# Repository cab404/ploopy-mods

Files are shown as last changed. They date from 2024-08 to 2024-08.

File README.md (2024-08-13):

cab's ploopy mods
====

This repo contains several of my small projects aimed to make Ploopy Headphones more comfortable for me — and maybe for you too.

They are mostly in dense OpenSCAD.

## [Newcap](./newcap/)

Stock magnet holders (driver caps) are not optimized for volume output.
This model improves volume dramatically (20dB+) by tweaking distance to the driver, magnet alignment and openness.

## [Headband](./headband/)

Ploopy headband is comfortable, but is not fit for listening on the move.
This model sits tighter — tight enough to  ride on an electric scooter — yet is still comfortable enough to enjoy.

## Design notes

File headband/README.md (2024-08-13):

Headband
====

I am currently using [r=50 without coils](./export/band+coils=....0+th=....2+r=...50.stl).

## How to choose

The lower the `r`, the more closed default position is.
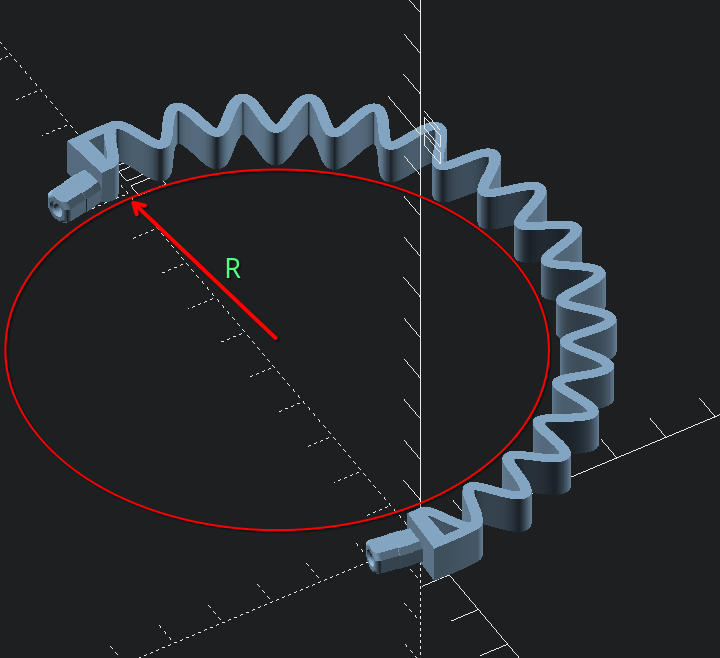
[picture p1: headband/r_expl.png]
image showing radius parameter


Thickness (`th`) can increase clamping force, but may also result in more brittle prints.

With [th=4 and r=30](./export/band+coils=....0+th=....4+r=...30.stl) you'll most probably get watermelon-between-thighs type of fit, so this repo truly offers wide range of experiences.

I haven't really experimented with number of coils yet, but I guess more coils can increase cushoning?
They do look kinda fun, and I've spent some time programming them, so do give them a try and report <3

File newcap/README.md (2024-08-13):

Newcap
====
This took forever, but they sure do plop louder now.
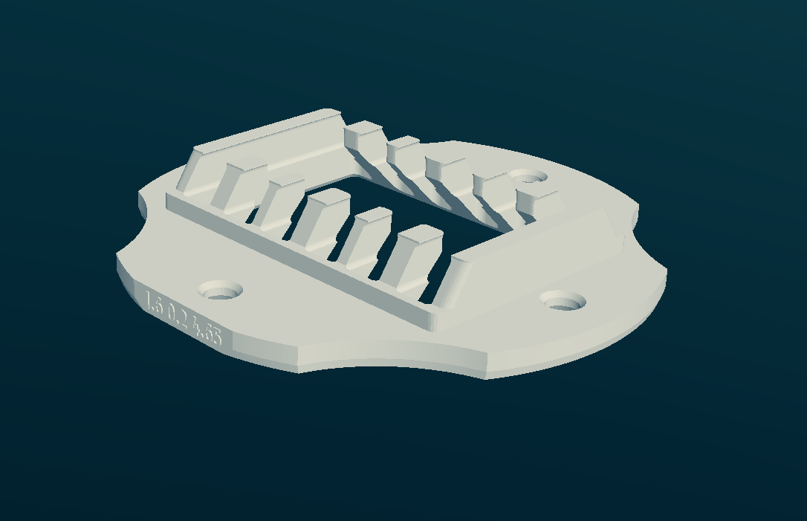
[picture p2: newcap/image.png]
open cap image, just for title

I am using [open 1.6 with 4.5 magnets, on 0.2 layer height](export/newcap+magnet_size=..4.5+open=..yes+h=..1.6+layer_height=..0.2.stl).

## How to choose

`magnet_size`: First of all, check your magnet width. It is usually 4.5mm, but I've encountered stock magnets being 4.8mm. Please report if you have some other different magnets.

`open`: This controls whether the holder exposes the driver, making the sound a lot more open, but also giving a lot more surface area for metal shavings and junk to stick to.

I find open variant nicer, and with less distortions, but Oratory is yet to test any of those caps on professional equipment.

`h`: This controls distance to inducer. The higher the value, the closer the magnets are.
Default is 1.6, but there is some variation in driver assemblies, so you might enjoy higher volumes on 1.8+ without any distortion.

`layer_height`: Top layer depends on print layer height. Printing on 0.1 can save you 0.1mm of potential travel for inducer, so it is recommended.

## How to install

You will either need either to cut some plastic from stock drivers or print [ones Xylite modelled](https://www.thingiverse.com/thing:6560552).

### Cutting plastic
You'll need to remove several perimeters (0.5mm) from the sides of driver frames, so the cap can with with magnets.

Here you can see where exactly you should cut:
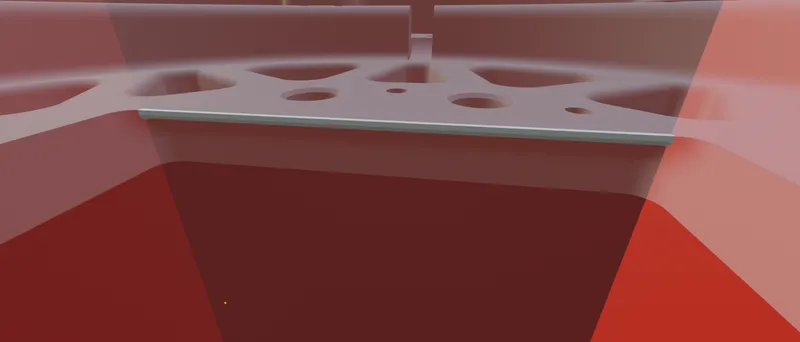
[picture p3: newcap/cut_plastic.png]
cut here


**Cut with drivers disassembled** if you are not completely sure that you won't destroy your inducer in the process.

Ploopy wiki for how to assemble the drivers back is [here](https://github.com/ploopyco/headphones/wiki/Part-2%3A-Drivers).

Don't rush.

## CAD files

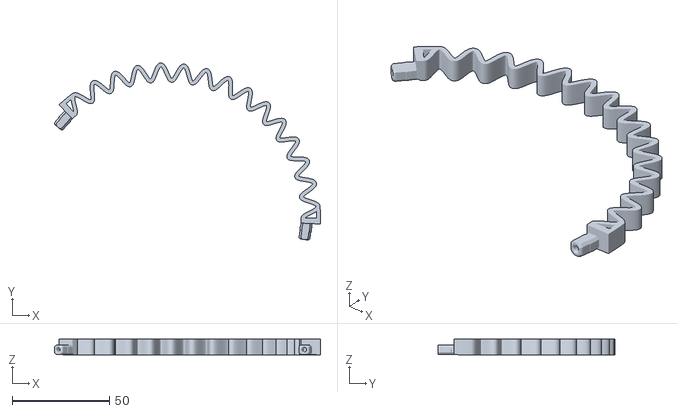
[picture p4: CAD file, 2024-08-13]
headband/export/band+coils=...15+th=....2+r=...70.stl
137.0 x 91.3 x 8.00

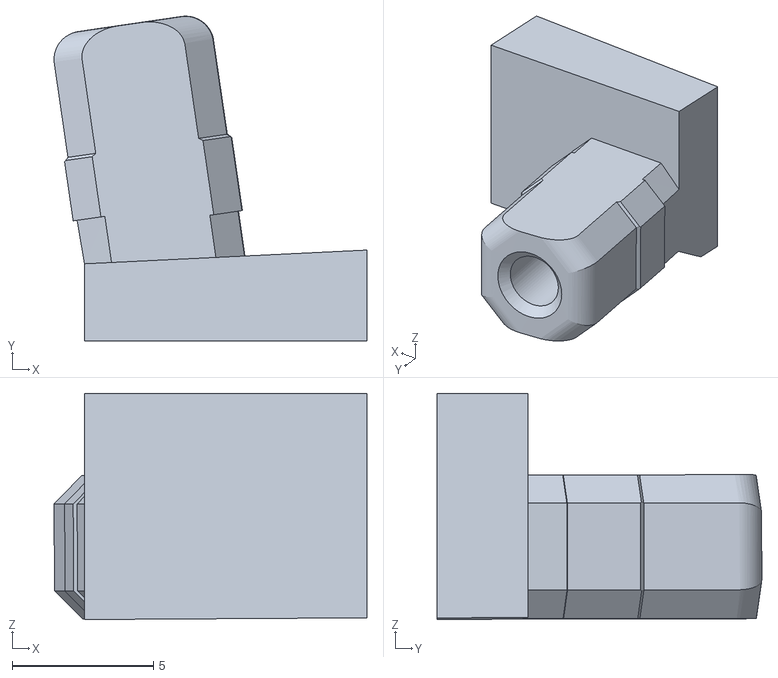
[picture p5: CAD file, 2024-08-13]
headband/pin.stl
11.1 x 11.5 x 8.00

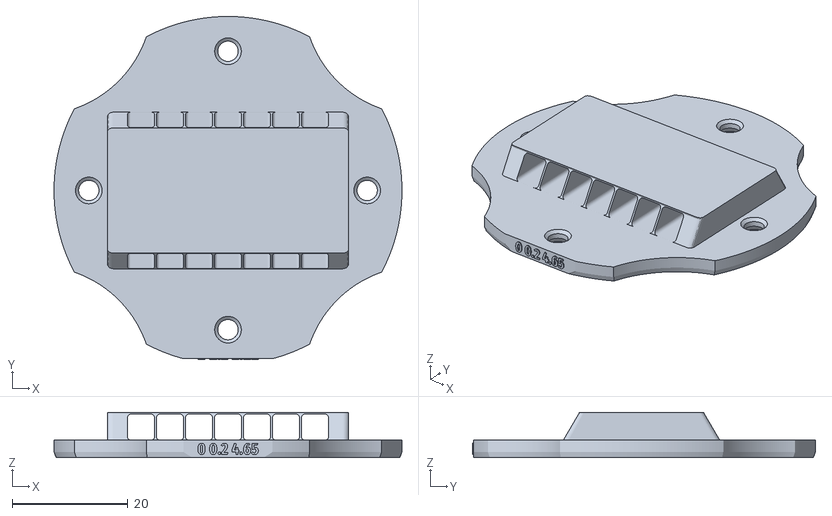
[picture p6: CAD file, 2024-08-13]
newcap/experiments/hallbachcap.stl
60.0 x 59.1 x 7.80

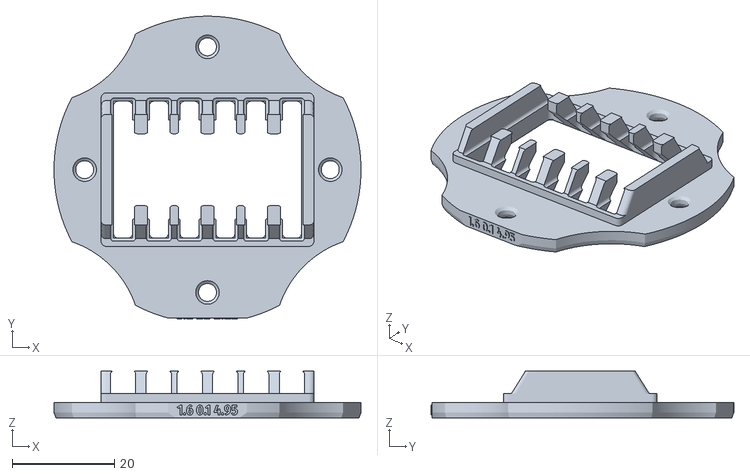
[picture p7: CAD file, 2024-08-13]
newcap/export/newcap+magnet_size=..4.8+open=..yes+h=..1.6+layer_height=..0.1.stl
60.0 x 59.1 x 9.10

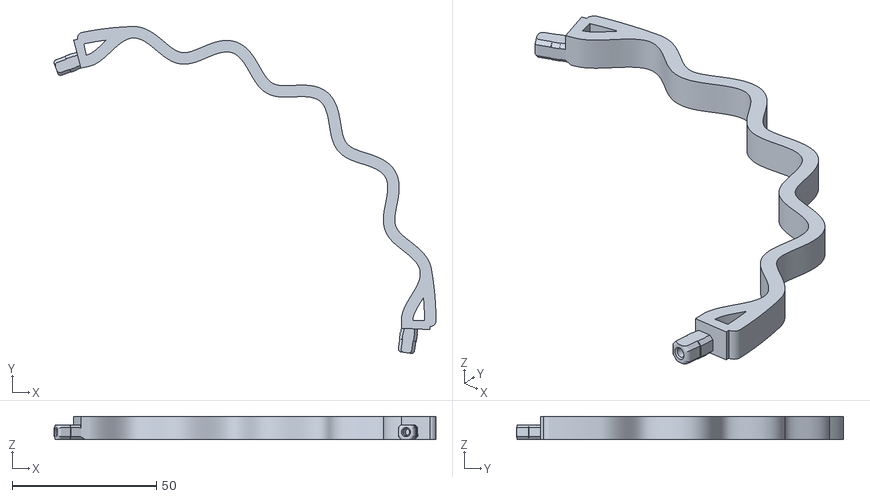
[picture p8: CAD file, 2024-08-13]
headband/export/band+coils=....5+th=....4+r=...90.stl
132.3 x 113.3 x 8.00

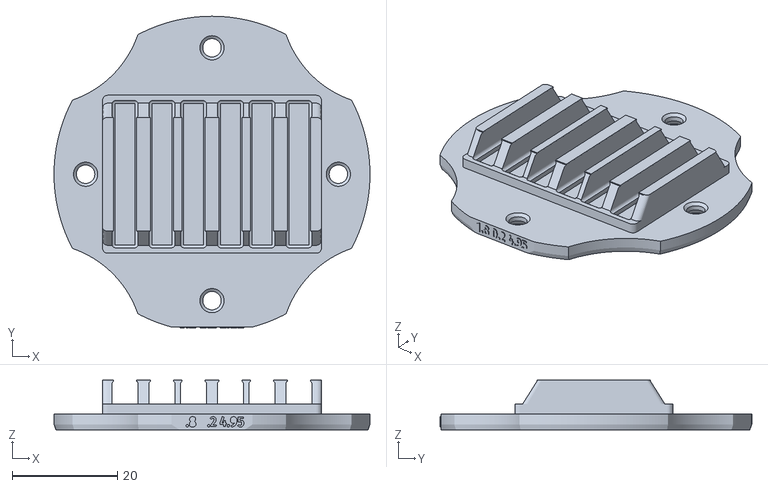
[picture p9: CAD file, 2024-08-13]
newcap/export/newcap+magnet_size=..4.8+open=...no+h=..1.8+layer_height=..0.2.stl
60.0 x 59.1 x 9.40

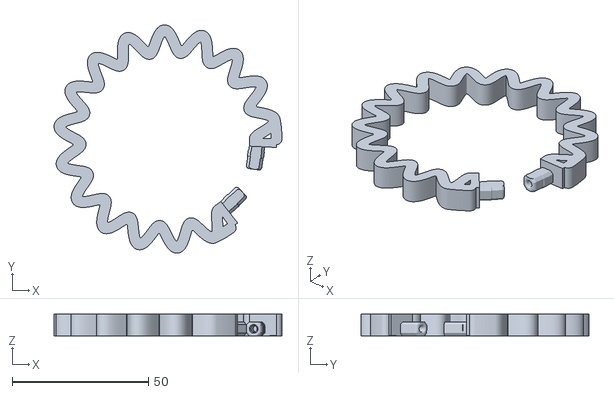
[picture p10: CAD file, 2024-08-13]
headband/export/band+coils=...15+th=....4+r=...30.stl
83.7 x 83.8 x 8.00

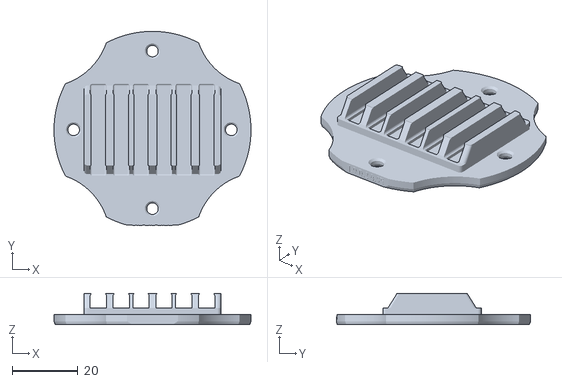
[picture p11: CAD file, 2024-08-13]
newcap/export/newcap+magnet_size=..4.8+open=...no+h=..1.9+layer_height=..0.2.stl
60.0 x 59.1 x 9.50

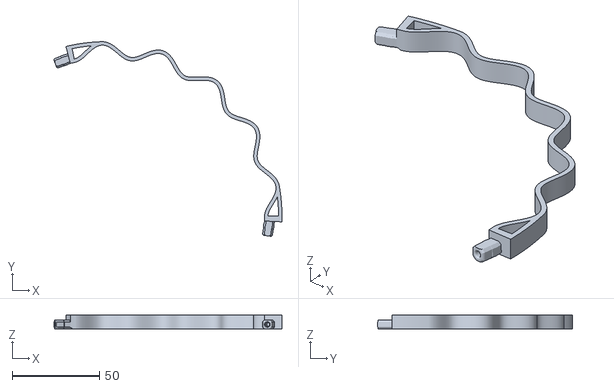
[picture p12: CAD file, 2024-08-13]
headband/export/band+coils=....5+th=....2+r=...90.stl
130.3 x 111.3 x 8.00

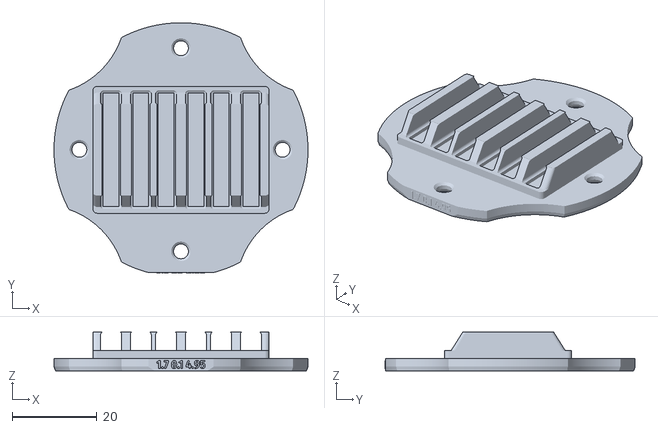
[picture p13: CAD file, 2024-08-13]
newcap/export/newcap+magnet_size=..4.8+open=...no+h=..1.7+layer_height=..0.1.stl
60.0 x 59.1 x 9.20

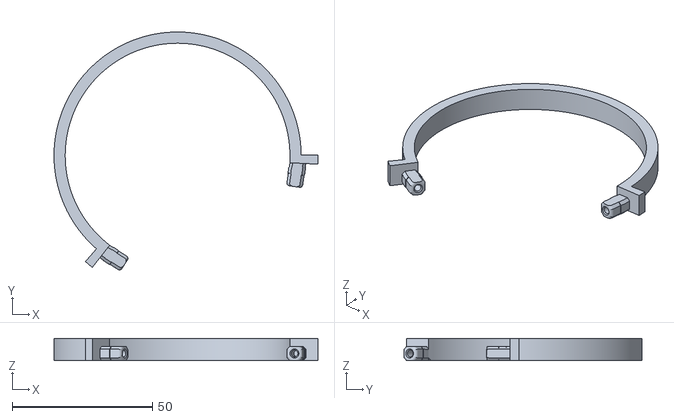
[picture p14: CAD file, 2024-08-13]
headband/export/band+coils=....0+th=....4+r=...40.stl
94.0 x 84.7 x 8.00

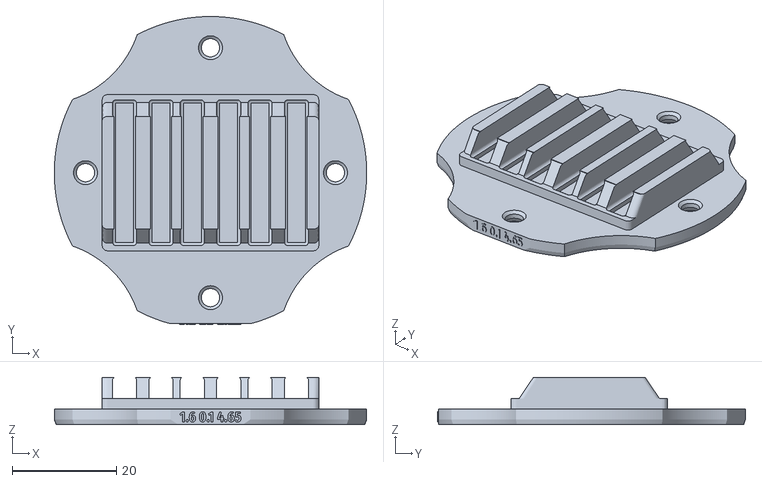
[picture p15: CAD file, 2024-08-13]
newcap/export/newcap+magnet_size=..4.5+open=...no+h=..1.6+layer_height=..0.1.stl
60.0 x 59.1 x 9.10

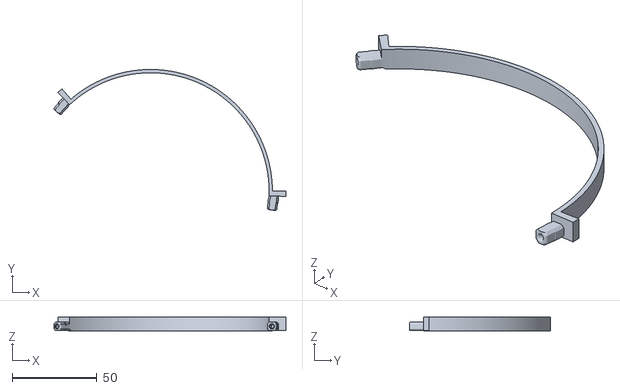
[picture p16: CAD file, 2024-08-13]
headband/export/band+coils=....0+th=....2+r=...70.stl
137.0 x 83.3 x 8.00

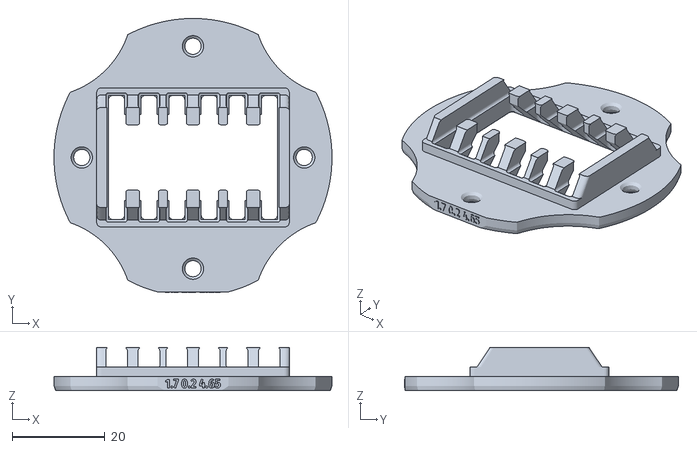
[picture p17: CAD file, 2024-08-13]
newcap/export/newcap+magnet_size=..4.5+open=..yes+h=..1.7+layer_height=..0.2.stl
60.0 x 59.1 x 9.30

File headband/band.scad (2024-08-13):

l = 160; // default: 160 from standard ploopy bands
r = 50; // default: 90 from standard ploopy bands
coils = 16; // 0 to disable coiling
ampl = 4; // amplitude for coils
th = 2; // thickness of the band
h = 8;
sharpest_point=0.25;
points_per_degree = 5;

// These are weird-ish.
// You can get non-flat springs with this.

// extrude_scale = 0.9;
// xoff=5;

extrude_scale = 1;
xoff=0;

$fn=30;


module pin() {
    translate(v = [xoff,-0.16,0])
    import("./pin.stl");
}

function sinarc(r, ang, ampl, points) = [ for (i=[0:points-1]) each let (
    a=i/points*ang,
    p=i/points,
    off = cos(p*360*coils+180)*ampl
    )[
    [ (r+off) * cos(a), (r+off) * sin(a) ]
] ];

module wavyarc(arc, ampl, r, points) {
    offset(r = -sharpest_point)
    offset(r = sharpest_point)
    offset(r = th/2)
    let (r=r+ampl+th/2)
    polygon(
        points = concat(
            sinarc(r-0.00001, arc, ampl, points),
            sinarc(r+0.00001, arc, ampl, points)
        ),
        paths=[
            concat(
                [for (i=[0:(points-1)]) each i],
                [for (i=[(points*2-1):-1:(points+1)]) each i]
            )
        ]
    );
}

// for (r = [50,60,70,80,90])
translate(v = [-r,0])
union() {

    ang = l / (PI * r) * 180;
    rotate(a = ang, v = [0,0,1])
    translate(v = [r,0,0])
    pin();

    translate(v = [r,0,0])
    scale(v = [-1,1,1])
    rotate(a = 180, v = [0,0,1])
    pin();

    linear_extrude(height = h,scale=extrude_scale)
    {
        wavyarc(ang, ampl, r, ceil(points_per_degree * ang));
        if (coils > 0) {
            wavyarc(ang/coils/2, 0, r+ampl*2, ceil(points_per_degree * (ang/coils/2)));
            rotate(a = ang-ang/coils/2)
            wavyarc(ang/coils/2, 0, r+ampl*2, ceil(points_per_degree * (ang/coils/2)));
        }
    }

}

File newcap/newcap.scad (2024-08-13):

// decoupled width and height to accomodate sog and expansion better
// [4.6, 4.65, 4.7]


// used for generating top magnet retaining layer
layer_height = 0.2;


_old_offsets = [ -16, -9.5, -3.5, 3.5, 9.5, 16 ];
_new_offsets = [ -16.5, -9.5, -3.5, 3.5, 9.5, 16.5 ];
// Stock offsets are not correctly aligned to the coils. As I don't know the intention behind that, I leave an option to disable that.
use_fixed_offsets = true;
magnet_offsets = use_fixed_offsets ? _new_offsets : _old_offsets;

// How high are the magnets above the baseplate. Value you will experiment the most with. Adjusted later to 4.5 mm magnet height.
unadj_magnet_elevation = 1.6;
// How deep the magnet goes into the base
magnet_mount_lip = 0.4;
// Controls how much is cut from the top to get the mounts. Positive values yield full magnet enclosure.
magnet_mount_top = -0.1;

// Whether to generate a giant hole in the middle
open = false;

// How high is the base layer. Full height of the base is base_height + chamfer_height
base_height = 2;
chamfer_height = 1;
chamfer_angle = 20;

magnet_h = 4.5;  //4.5, 4.8
magnet_w = magnet_h + 0.15; //4.65, 4.95
magnet_length=28;
magnet_bevel = 0.6;

bottom_holder_scale = 0.9;
top_holder_scale = 0.8;

module endofparams() {} // so customizer doesn't see what's below


magnet_elevation = unadj_magnet_elevation + (4.5 - magnet_h);

outer_radius = 30;
mounting_hole_dst = 48;
mounting_hole_diam = 3.5;

module mounting_hole() {
    $fn=40;
    h = 30;
    render() // for better thrown-together view
    translate(v = [0,0,- h - (mounting_hole_diam/2)])
    union() {
        translate(v = [0,0,h + (mounting_hole_diam/2)])
        cylinder(h = h, r = mounting_hole_diam);
        translate(v = [0,0,h])
        linear_extrude(height = (mounting_hole_diam/2), scale=2)
        circle(r = mounting_hole_diam / 2);
        cylinder(h = h, r = mounting_hole_diam / 2);
    }
}

module base_outline() {
        let($fn=300)
        difference() {
            circle(r = outer_radius);
            for (i=[1,-1], j=[1,-1]) {
                translate(v = [33*i,33*j])
                circle(r = 20);
            }
        }
}

module base() {
    translate(v = [0,0,-(chamfer_height + base_height)])
    let($fn=300)
    union() {
        let(scl=tan(chamfer_angle))
        linear_extrude(height = chamfer_height, scale=outer_radius/(outer_radius - (chamfer_height*scl)))
        scale(v = (outer_radius - (chamfer_height*scl))/outer_radius)
        base_outline();
        translate(v = [0,0,chamfer_height])
        linear_extrude(height = base_height)
        base_outline();
    }
}

module magnet() {
    $fn=42;
    off = -(magnet_bevel*2);
    render()
    minkowski() {
        cube(center=true, size = [magnet_w+off, 28+off, magnet_h+off, ]);
        sphere(r = magnet_bevel);
    }
}

module raise(h) {
    translate(v = [0,0,h]) children();
}

module square_base() {
    minkowski() {
        $fn=20;

        circle(r = 1);
        square(center=true, size = [41.6-2,28]);
    };
}

module magnet_holder() {
    difference() {
        let(h=magnet_elevation + magnet_mount_lip)
        union() {
            translate(v = [0,0,-0.1])
            linear_extrude(height = magnet_elevation + magnet_mount_lip + 0.1)
            square_base();
            raise(h)
            linear_extrude(height = magnet_h - magnet_mount_lip + magnet_mount_top, scale=[1,top_holder_scale])
            scale(v = [1,bottom_holder_scale])
            square_base();
        }


        for (off=magnet_offsets)
        translate(v = [off, 0, magnet_elevation + magnet_h / 2]) {

            // a little pocket under magnets so surface imperfections won't affect fit
            let(pocket_depth = 0.9)
            translate(v = [0,0,-pocket_depth])
            cube(center=true, size = [
                magnet_w - magnet_bevel*2,
                magnet_length - magnet_bevel*2,
                magnet_h
            ]);
            magnet();
        }
    }
}

module mount() {
    difference()  {

        // base
        base();

        // mounting holes
        for (ang=[0:90:360]) {
            union() {
                rotate(a = ang, v = [0,0,1])
                translate(v = -[0,mounting_hole_dst/2,chamfer_height+base_height+0.2])
                rotate(a = 180,v=[1,0,0])
                mounting_hole();

                // small chamfer for tapped out material to sit in
                rotate(a = ang, v = [0,0,1])
                translate(v = -[0,mounting_hole_dst/2,-1.2])
                mounting_hole();
            }
        }
    }
}

module assemble() {
    magnet_holder();
    mount();

    // A lip on top
    let(source_h=magnet_elevation + magnet_h + magnet_mount_top - 0.0001)
    raise(source_h)
    linear_extrude(height = layer_height)
    projection(cut=true)
    raise(-source_h)
    magnet_holder();
}

module render_magnets() {
        color(c = "#333333")
        for (off=magnet_offsets)
        translate(v = [off, 0, magnet_elevation + magnet_h / 2])
        magnet();
}

// that weird hole shape
module seethru() {
    offset(r=1)
    offset(r=-2)
    offset(r=1) {
        square(size = [34.45,14], center=true);
        for (off=magnet_offsets) {
            square(size = [32.45,12], center=true);
            translate(v = [off, 0]) {
                // a little pocket under magnets so surface imperfections won't affect fit
                let(pocket_depth = 1.9)
                translate(v = [0,0,-pocket_depth])
                square(center=true, size = [
                    magnet_w - magnet_bevel*2,
                    magnet_length - magnet_bevel*2
                ]);
            }
        }
    }
}

difference() {
    translate(v = [0 ,0,base_height + chamfer_height])
    assemble();

    // info text
    let($fn=100, cut=1, depth=0.15)
    difference(){
        translate(v = -[0, outer_radius-cut/2, 0])
        cube(size = [100,cut + 0.01,100], center=true);

        color(c = "#ff0000")
        #translate(v = -[0, outer_radius-cut-0.01, 0])
        translate(v = [0, 0, (chamfer_height + base_height) / 2])
        rotate(a = 90, v = [1,0,0])
        linear_extrude(height = depth+0.01)
        text(text = str(unadj_magnet_elevation, " ", layer_height, " ", magnet_w), valign="center", halign="center", size=2, font="Fira Sans Condensed:style=Bold");
    }
    render(convexity=4)
    if (open) {
        let($fn=40)
        linear_extrude(height = 30,center=true,convexity=3)
        seethru();

        let($fn=40, hole=[38,28])
        linear_extrude(height = 1, scale=[(hole[0]-2)/hole[0], (hole[1]-2)/hole[1]])
        // offset(r=1)
        offset(r=1)
        offset(r=-1)
        square(size=hole, center=true);

        let($fn=40, hole=[36,28])
        linear_extrude(height = 10, scale=[1, (hole[1]-20)/hole[1]])
        // offset(r=1)
        offset(r=1)
        offset(r=-1)
        square(size=hole, center=true);
    }
    // let($fn=20)

    // linear_extrude(height = 1,center=true,convexity=3, scale=34.45/(34.45+2))
    // seethru();

    // rotate(a = 45, v = [1,0,0])
    // cube(size = [34.5,19,19], center=true);

}

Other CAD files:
headband/export/band+coils=....5+th=....2+r=...50.stl
newcap/export/newcap+magnet_size=..4.5+open=...no+h=..1.7+layer_height=..0.1.stl
headband/export/band+coils=....0+th=....2+r=...30.stl
newcap/export/newcap+magnet_size=..4.5+open=...no+h=..1.6+layer_height=..0.2.stl
newcap/experiments/halbach.scad
headband/export/band+coils=....0+th=....2+r=...40.stl
headband/export/band+coils=....0+th=....2+r=...50.stl
headband/export/band+coils=....0+th=....2+r=...90.stl
headband/export/band+coils=....0+th=....4+r=...30.stl
headband/export/band+coils=....0+th=....4+r=...50.stl
headband/export/band+coils=....0+th=....4+r=...70.stl
headband/export/band+coils=....0+th=....4+r=...90.stl
headband/export/band+coils=....1+th=....2+r=...30.stl
headband/export/band+coils=....1+th=....2+r=...40.stl
headband/export/band+coils=....1+th=....2+r=...50.stl
headband/export/band+coils=....1+th=....2+r=...70.stl
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
